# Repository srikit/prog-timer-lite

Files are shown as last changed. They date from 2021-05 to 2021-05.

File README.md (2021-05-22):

# Programmable Timer Module


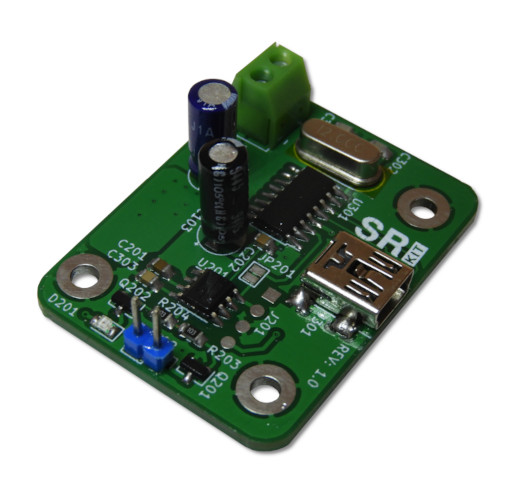
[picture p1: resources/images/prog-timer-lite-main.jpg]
Timer Module PCB


Programmable timer lite is a miniature, USB programmable timer module. This module can handle more than 100 alarm configurations and trigger the output channel based on the programmed conditions. The timer module can program using SRIKit's [*Timer Controller*](https://github.com/srikit/timer-controller) software. 

This module is designed around the *STM8S001J3M* microcontroller and *DS3231* real-time clock. *AMS1117-3.3* regulator in this module can handle a maximum of 9V DC input without installing an external heatsink. 

The alarm terminal of this module is available as an open-collector output. 

This module is specifically developed to handle long-duration alarm configurations which can span up to years. 

This is an open-source hardware project. All the design files, [documentation](https://github.com/srikit/prog-timer-lite/wiki), and firmware source code are available to download at the project source repository. Content of this project is distributed under the terms of the following license:

- Hardware License: [CERN-OHL-W](https://opensource.org/CERN-OHL-W)
- Software License: [GNU GPL 3.0](https://github.com/srikit/prog-timer-lite/blob/main/LICENSE)
- Documentation License: [CC BY 4.0](https://creativecommons.org/licenses/by/4.0)

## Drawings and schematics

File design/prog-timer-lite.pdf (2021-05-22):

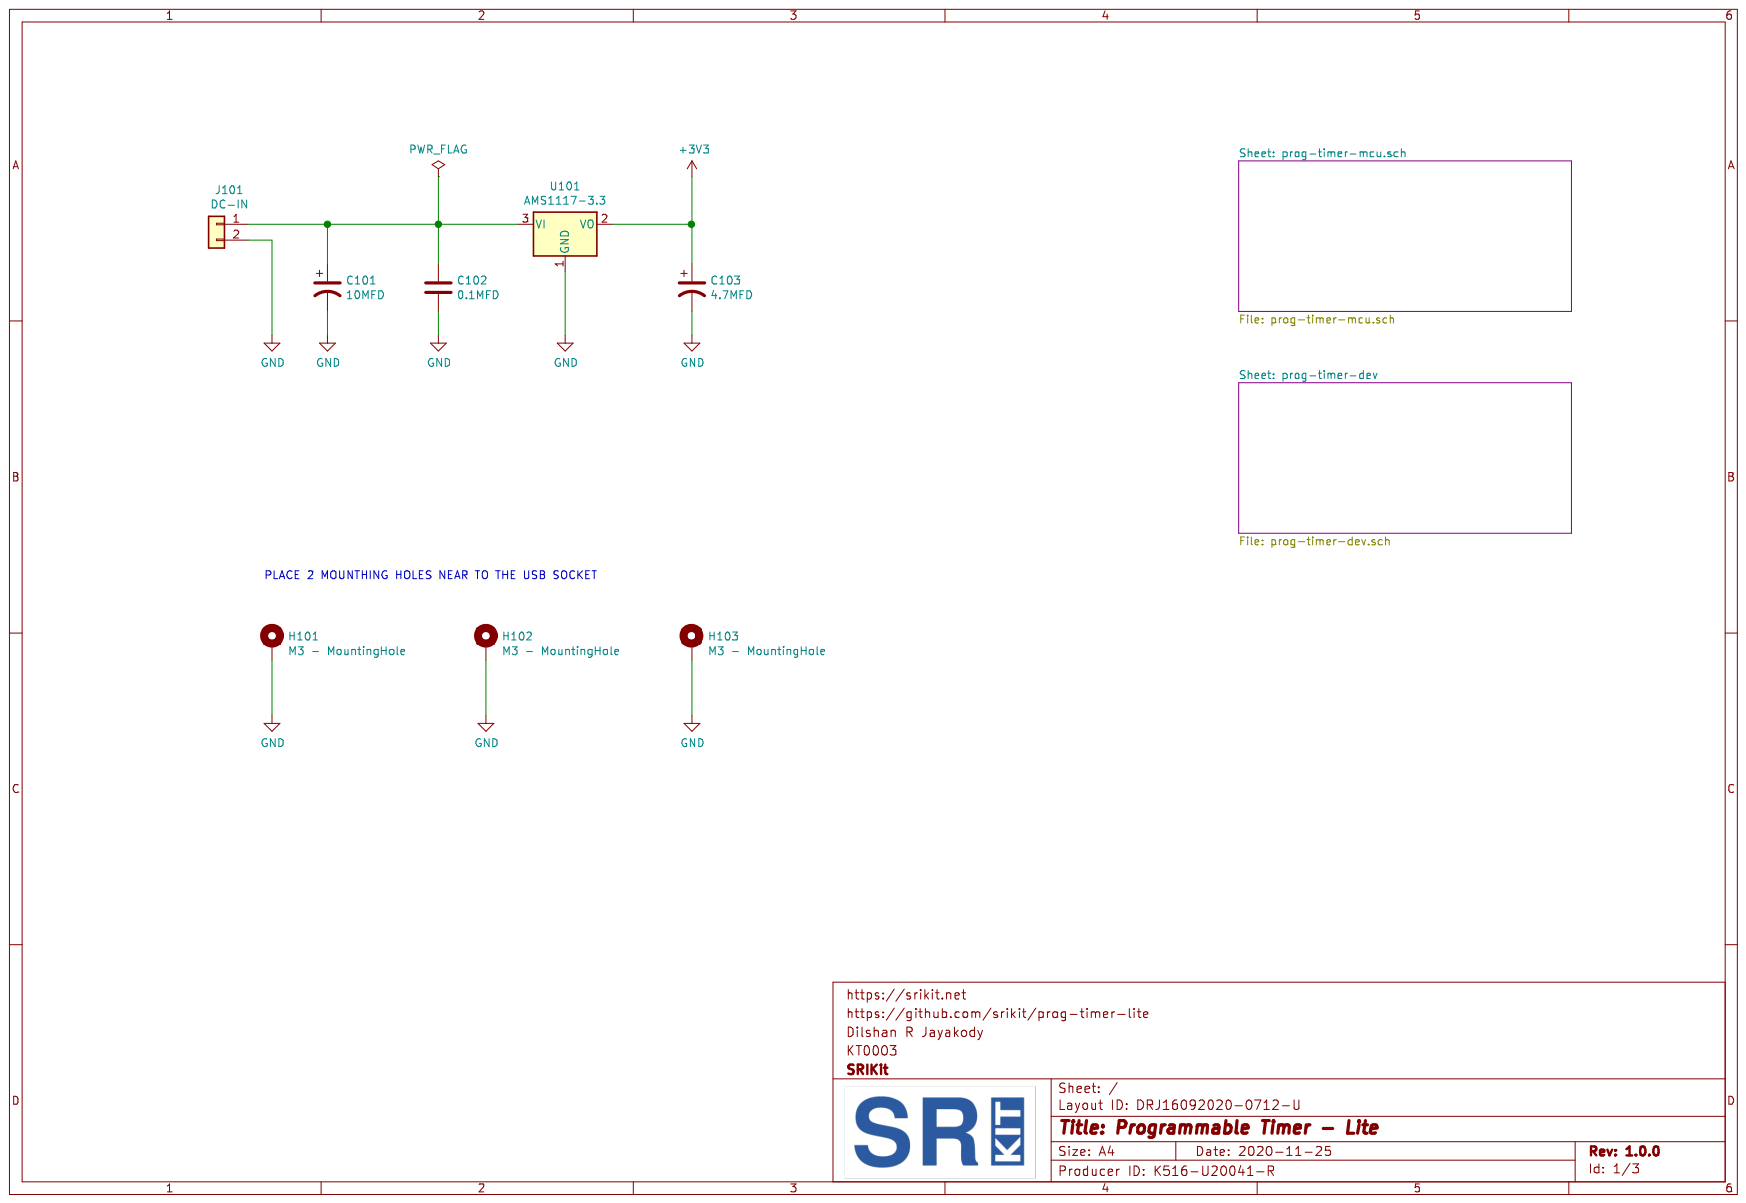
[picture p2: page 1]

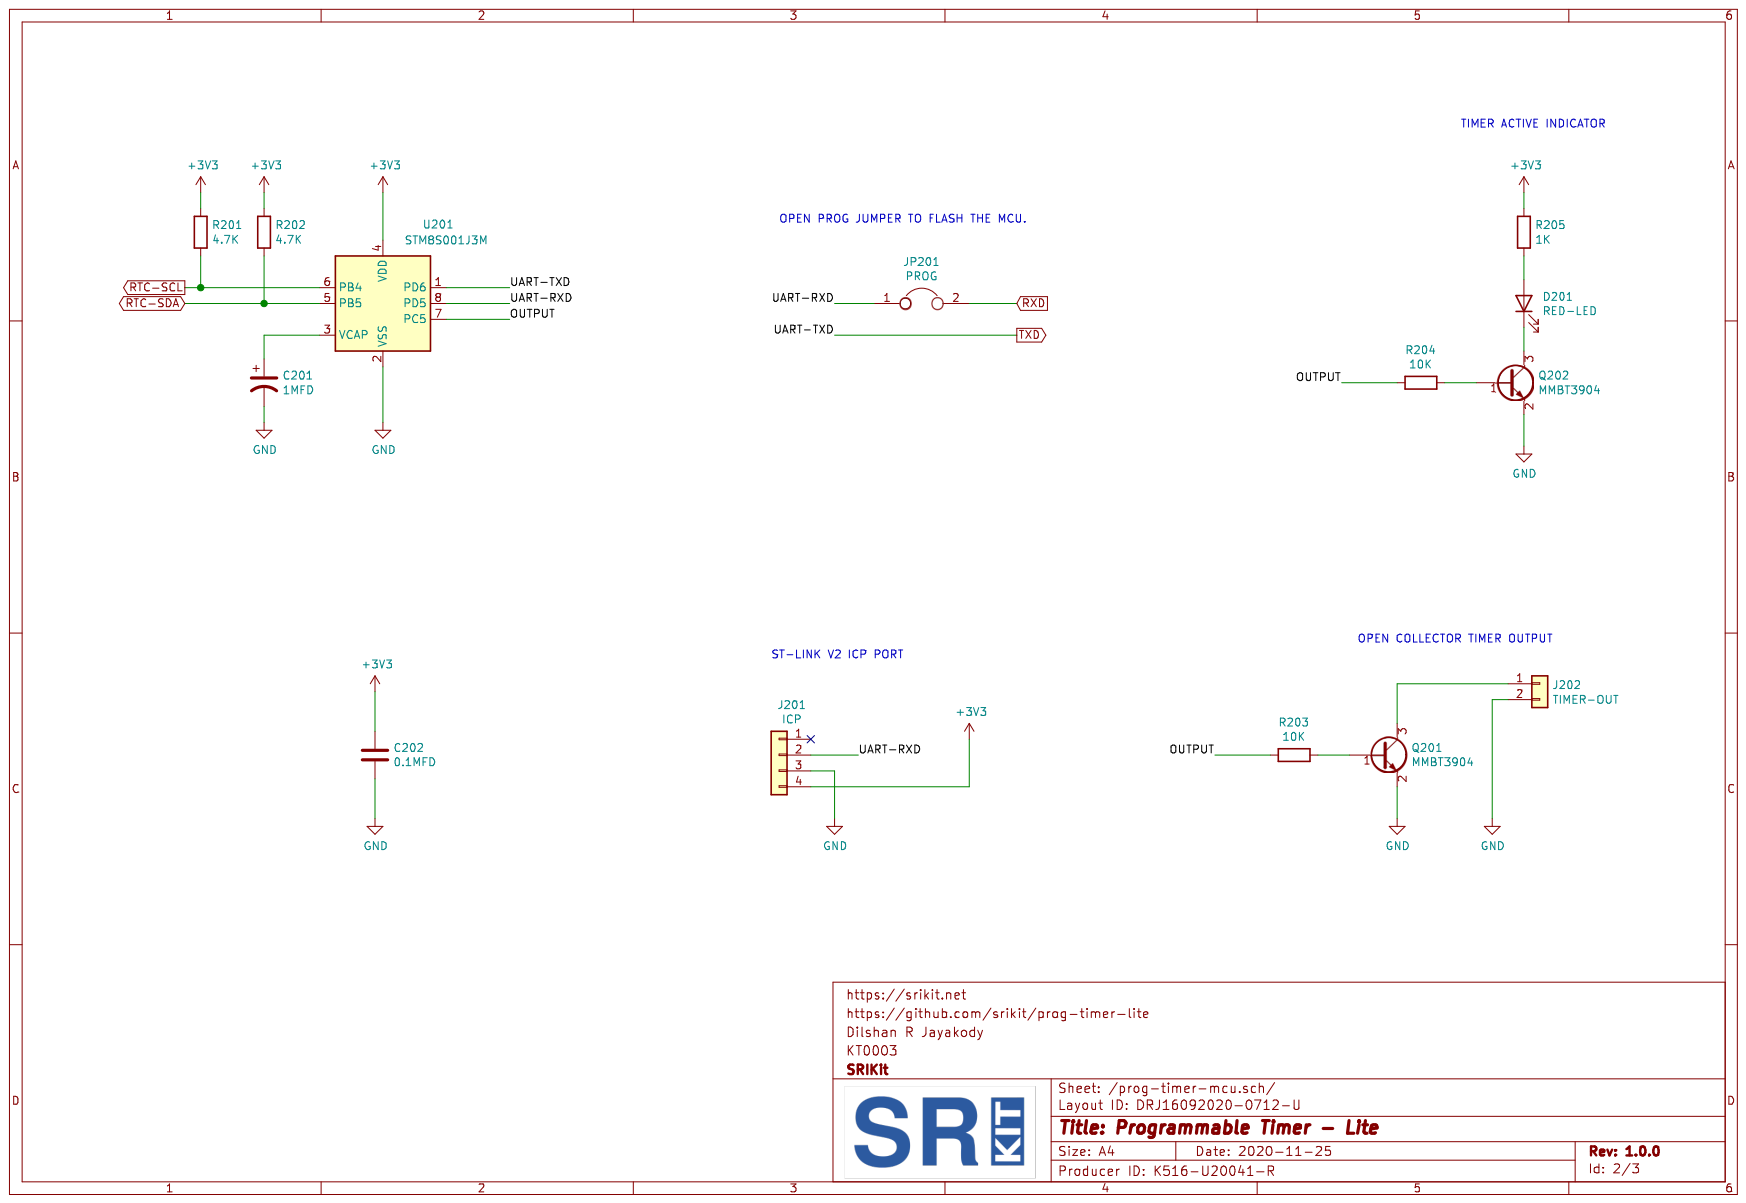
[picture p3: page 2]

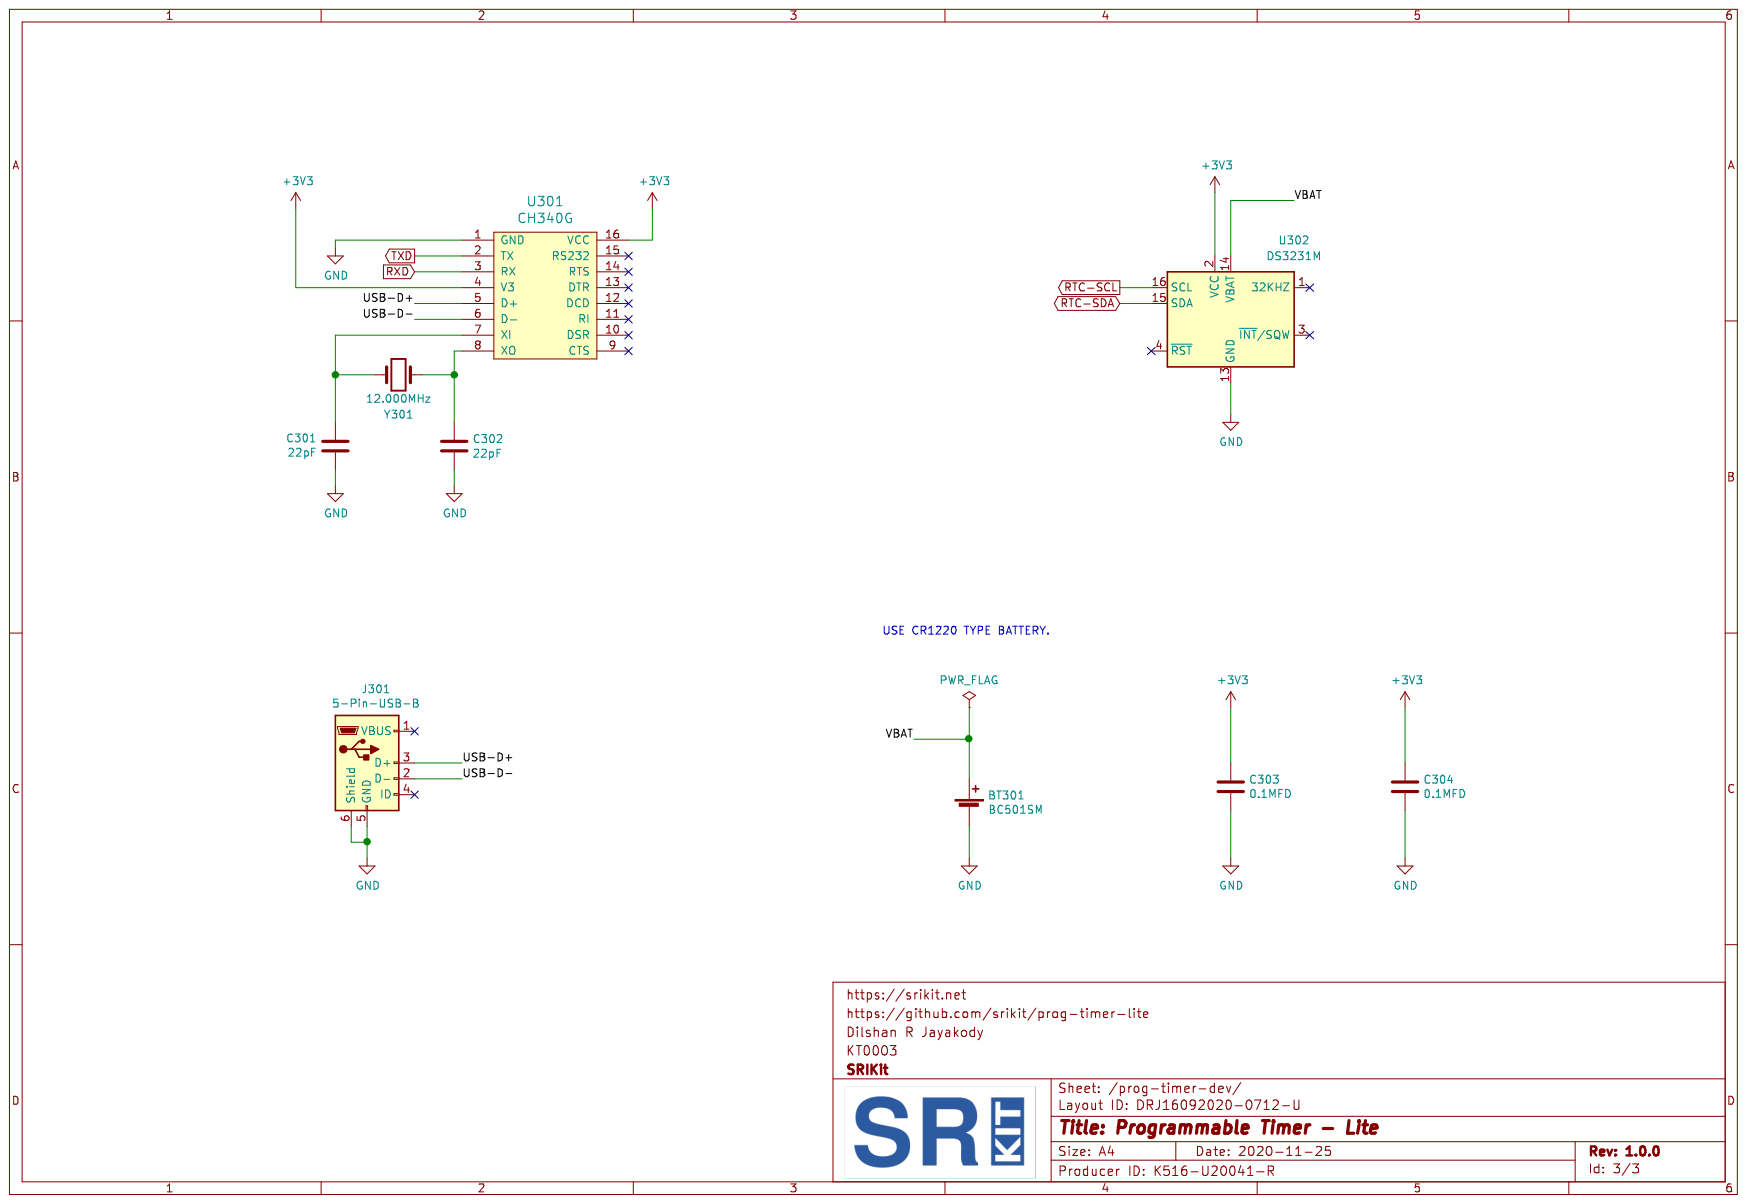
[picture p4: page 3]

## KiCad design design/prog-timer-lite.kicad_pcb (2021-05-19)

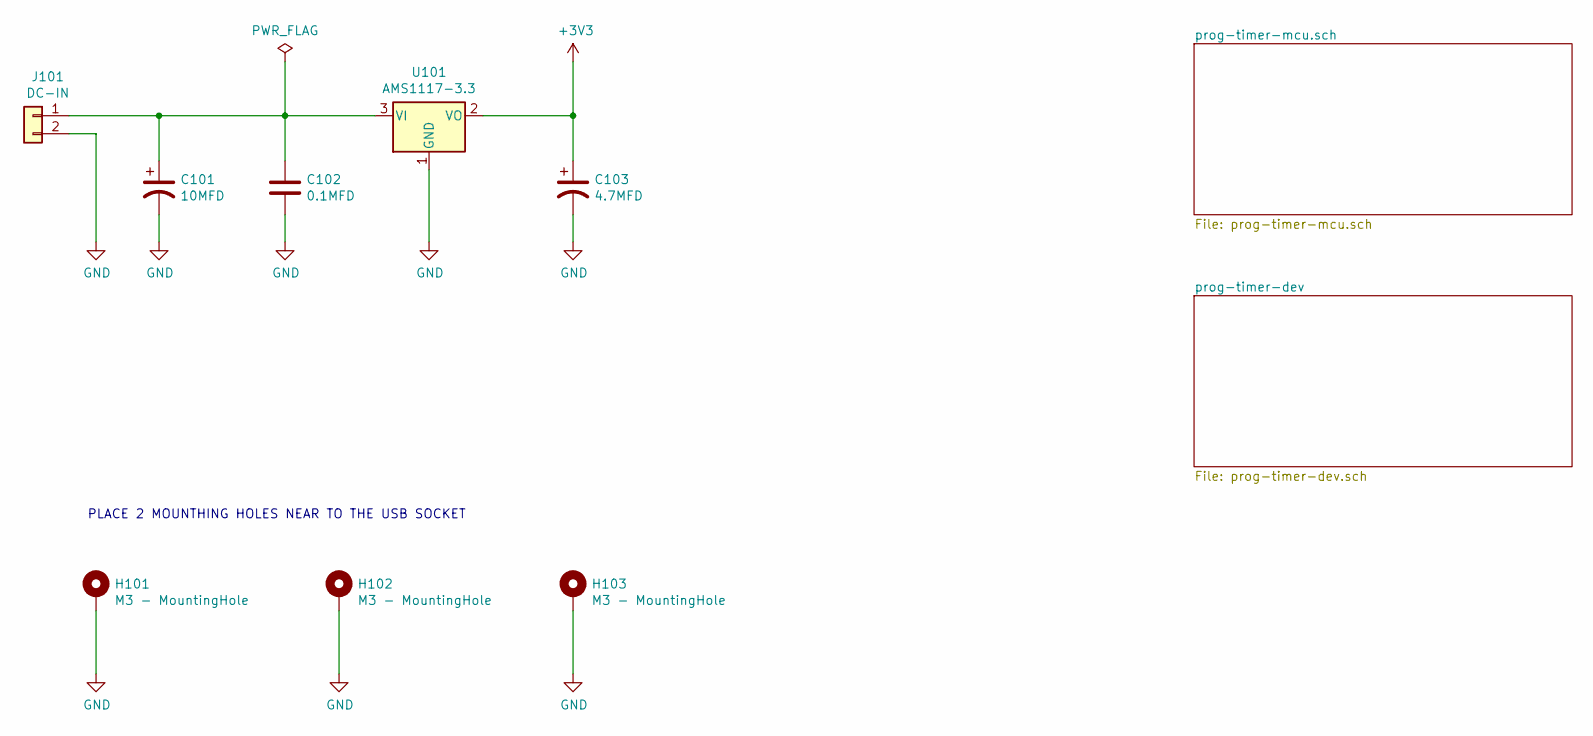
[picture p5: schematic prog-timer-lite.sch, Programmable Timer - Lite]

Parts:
C101: 10MFD; CP_Radial_D5.0mm_P2.50mm
C102: 0.1MFD; C_0805_2012Metric_Pad1.15x1.40mm_HandSolder
C103: 4.7MFD; CP_Radial_D5.0mm_P2.50mm
H101, H102, H103: M3 - MountingHole; MountingHole_3mm_Pad
J101: DC-IN; PhoenixContact_MCV_1,5_2-G-3.5_1x02_P3.50mm_Vertical
U101: AMS1117-3.3; SOT-223-3_TabPin2

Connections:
+3V3: C103.1, U101.2 (VO); also elsewhere on the board
GND: C101.2, C102.2, C103.2, H101.1, H102.1, H103.1, J101.2, U101.1 (GND); also elsewhere on the board
unnamed: C101.1, C102.1, J101.1, U101.3 (VI)

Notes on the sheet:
PLACE 2 MOUNTHING HOLES NEAR TO THE USB SOCKET

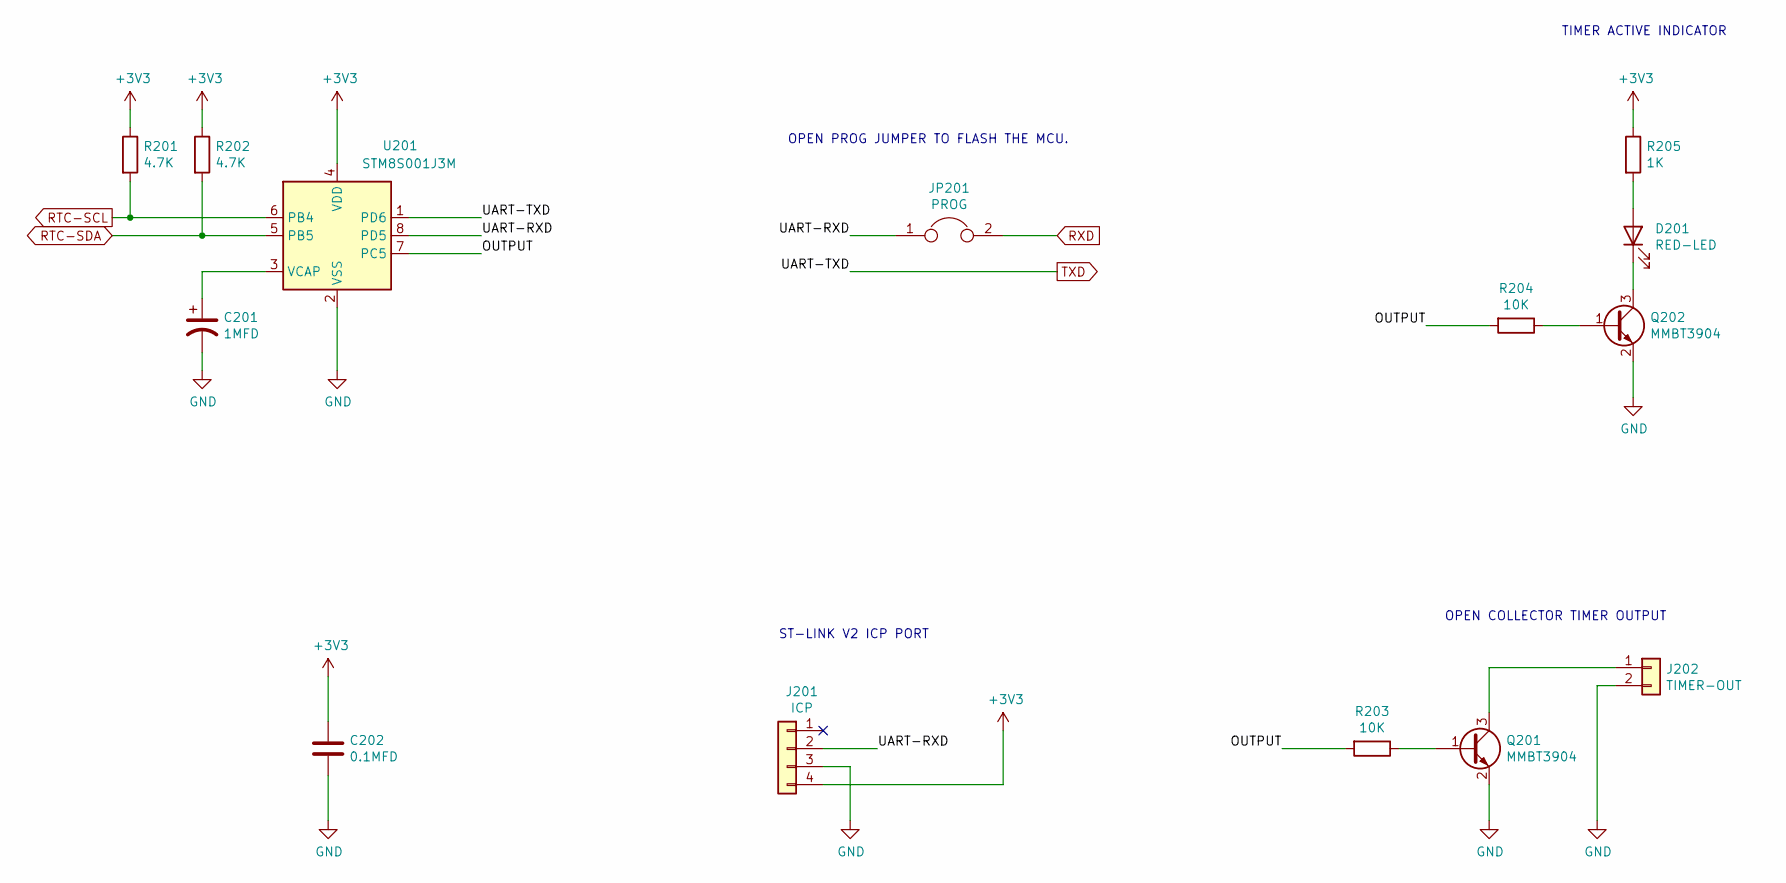
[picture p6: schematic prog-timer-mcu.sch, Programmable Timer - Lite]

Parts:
C201: 1MFD; C_0805_2012Metric_Pad1.15x1.40mm_HandSolder
C202: 0.1MFD; C_0805_2012Metric_Pad1.15x1.40mm_HandSolder
D201: RED-LED; LED_0805_2012Metric_Pad1.15x1.40mm_HandSolder
J201: ICP; pogo-2.54mmx4
J202: TIMER-OUT; PinHeader_1x02_P2.54mm_Vertical
JP201: PROG; SolderJumper-2_P1.3mm_Bridged_Pad1.0x1.5mm
Q201, Q202: MMBT3904; SOT-23
R201, R202: 4.7K; R_0805_2012Metric_Pad1.15x1.40mm_HandSolder
R203, R204: 10K; R_0805_2012Metric_Pad1.15x1.40mm_HandSolder
R205: 1K; R_0805_2012Metric_Pad1.15x1.40mm_HandSolder
U201: STM8S001J3M; SO-8_3.9x4.9mm_P1.27mm

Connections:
+3V3: C202.1, J201.4, R201.1, R202.1, R205.1, U201.4 (VDD); also elsewhere on the board
/prog-timer-mcu.sch/OUTPUT: R203.2, R204.2, U201.7 (PC5)
/prog-timer-mcu.sch/UART-RXD: J201.2, JP201.1, U201.8 (PD5)
GND: C201.2, C202.2, J201.3, J202.2, Q201.2 (E), Q202.2 (E), U201.2 (VSS); also elsewhere on the board
unnamed: C201.1, U201.3 (VCAP)
unnamed: D201.1 (K), Q202.3 (C)
unnamed: D201.2 (A), R205.2
unnamed: J202.1, Q201.3 (C)
unnamed: Q201.1 (B), R203.1
unnamed: Q202.1 (B), R204.1
RTC-SCL: R201.2, U201.6 (PB4); also elsewhere on the board
RTC-SDA: R202.2, U201.5 (PB5); also elsewhere on the board
RXD: JP201.2; also elsewhere on the board
TXD: U201.1 (PD6); also elsewhere on the board

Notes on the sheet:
OPEN PROG JUMPER TO FLASH THE MCU.
TIMER ACTIVE INDICATOR
ST-LINK V2 ICP PORT
OPEN COLLECTOR TIMER OUTPUT

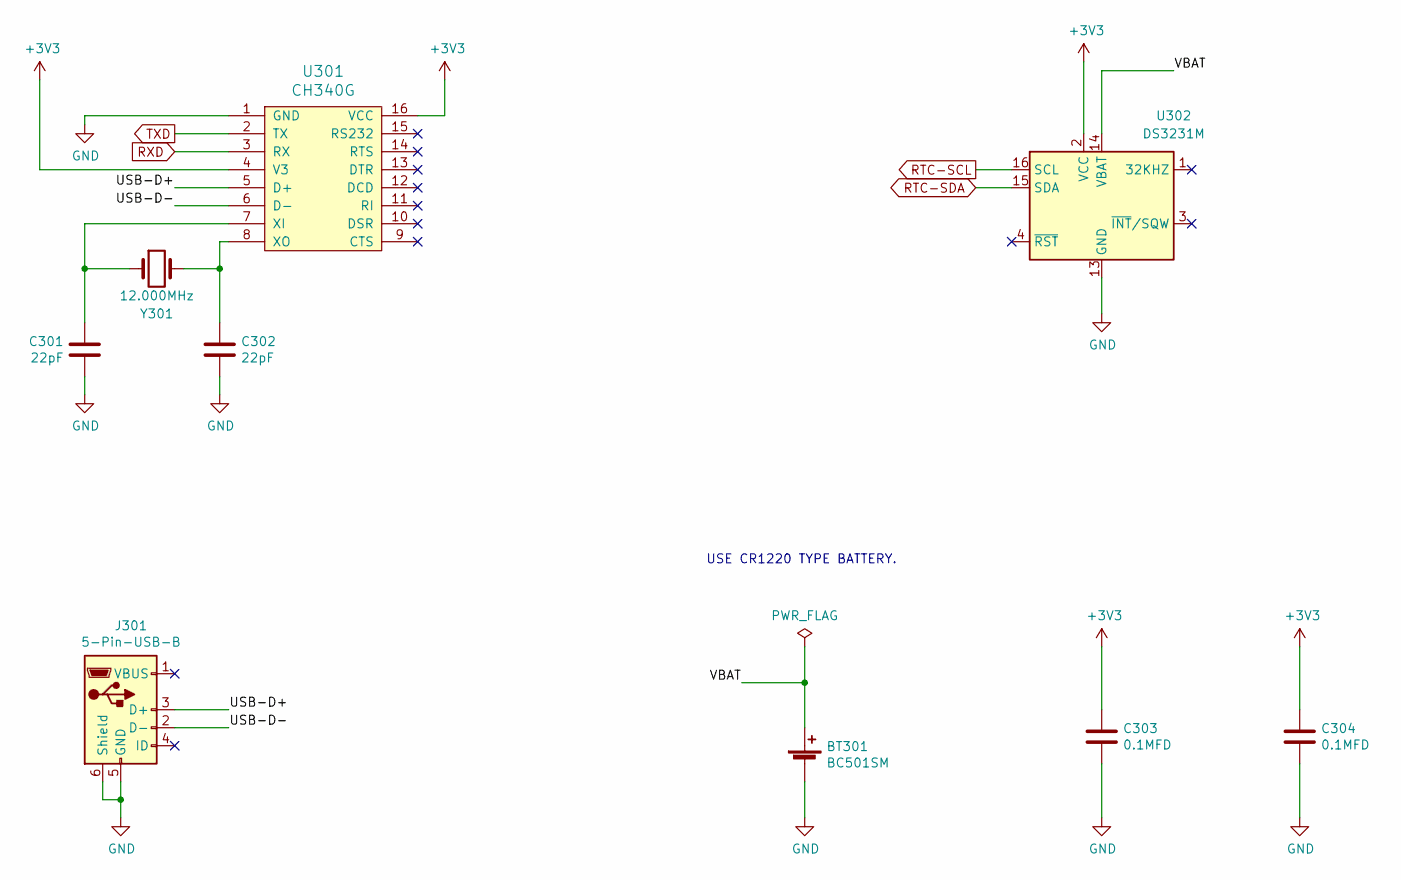
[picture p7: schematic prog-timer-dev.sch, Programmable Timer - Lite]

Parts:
BT301: BC501SM; MPD_BC501SM-TR
C301, C302: 22pF; C_0805_2012Metric_Pad1.15x1.40mm_HandSolder
C303, C304: 0.1MFD; C_0805_2012Metric_Pad1.15x1.40mm_HandSolder
J301: 5-Pin-USB-B; USB_Mini-B_Wuerth_65100516121_Horizontal
U301: CH340G; SOP-16_4.55x10.3mm_P1.27mm
U302: DS3231M; SOIC-16W_7.5x10.3mm_P1.27mm
Y301: 12.000MHz; Crystal_HC49-U_Vertical

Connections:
+3V3: C303.1, C304.1, U301.4 (V3), U301.16 (VCC), U302.2 (VCC); also elsewhere on the board
/prog-timer-dev/USB-D+: J301.3 (D+), U301.5 (D+)
/prog-timer-dev/USB-D-: J301.2 (D-), U301.6 (D-)
/prog-timer-dev/VBAT: BT301.1 (+), U302.14 (VBAT)
GND: BT301.2 (-), C301.1, C302.2, C303.2, C304.2, J301.5 (GND), J301.6 (Shield), U301.1 (GND), U302.5 (GND), U302.6 (GND), U302.7 (GND), U302.8 (GND), U302.9 (GND), U302.10 (GND), U302.11 (GND), U302.12 (GND), U302.13 (GND); also elsewhere on the board
unnamed: C301.2, U301.7 (XI), Y301.1
unnamed: C302.1, U301.8 (XO), Y301.2
RTC-SCL: U302.16 (SCL); also elsewhere on the board
RTC-SDA: U302.15 (SDA); also elsewhere on the board
RXD: U301.3 (RX); also elsewhere on the board
TXD: U301.2 (TX); also elsewhere on the board

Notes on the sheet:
USE CR1220 TYPE BATTERY.

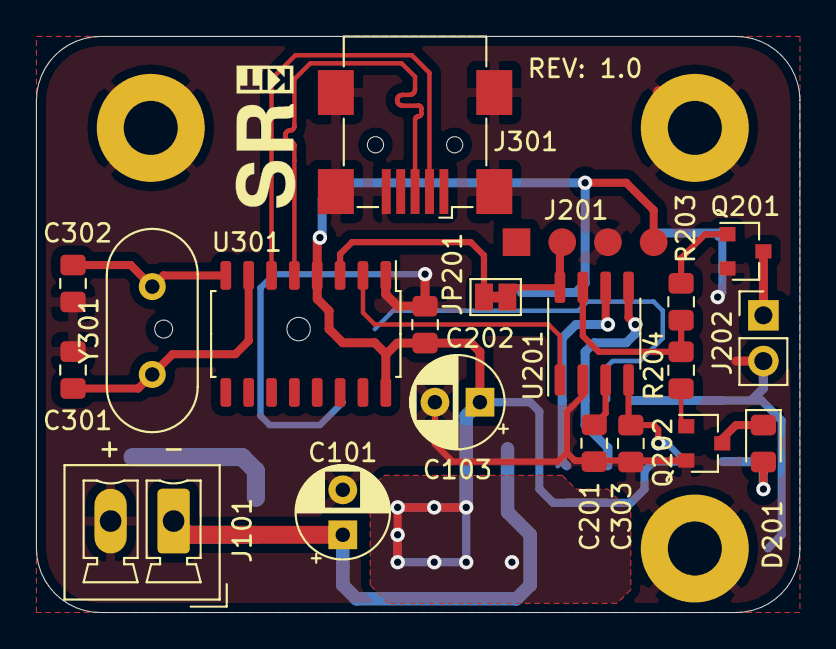
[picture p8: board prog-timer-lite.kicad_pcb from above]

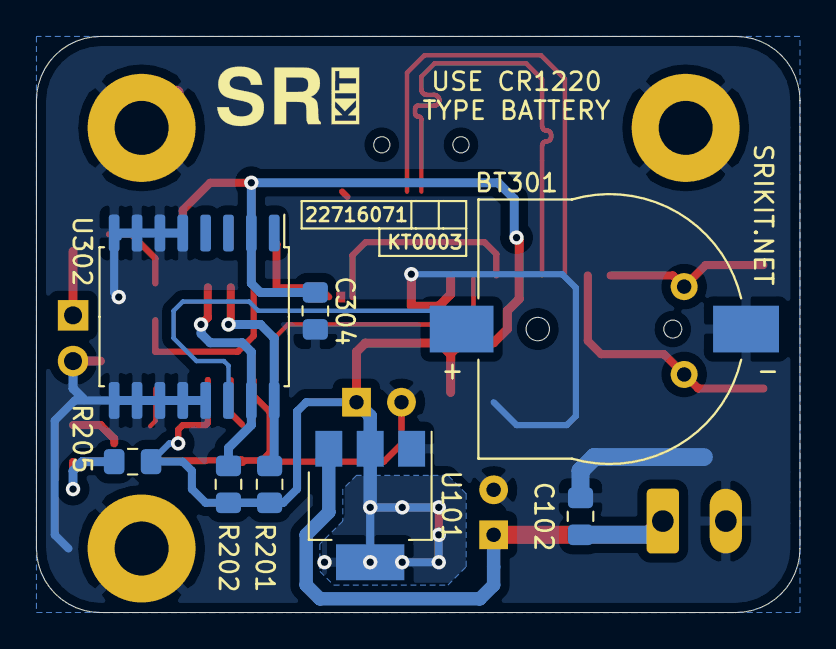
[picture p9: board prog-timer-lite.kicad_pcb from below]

Board: 2 copper layers, 42.4 x 32.0 mm, 31 parts (8 on the bottom side), 20 nets.

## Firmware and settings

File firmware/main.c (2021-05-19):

//-----------------------------------------------------------------------------
// Programmable Timer - Single Channel - Lite Version.
// Main source file.
// 
// Copyright (C) 2020 SriKIT contributors.
//
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
// Last updated: Dilshan Jayakody [24th Nov 2020]
//
// Update log:
// [24/11/2020] - Initial version - Dilshan Jayakody.
//-----------------------------------------------------------------------------

#include "include/stm8.h"
#include "include/stm8-util.h"
#include "include/stm8-uart.h"
#include "include/stm8-eeprom.h"

#include "main.h"
#include "commdata.h"
#include "commresponse.h"
#include "dataconv.h"

// Startup delay limit.
#define INIT_RESET_DELAY    157456

// Size of the input command buffer.
#define DATA_BUFFER_SIZE        19
#define EEPROM_DATA_BLOCK_SIZE  16

#define COMMAND_AVAILABLE   1
#define COMMAND_NOT_FOUND   0

#define ALARM_ON_OUT    0x38
#define ALARM_OFF_OUT   0x00

unsigned char dataBuffer[DATA_BUFFER_SIZE];

void UART_received() __interrupt(UART1_RX_IRQ)
{
    if(uartDataAvailable())
    {
        // UART data is available.  
        dataVal = uartGetByte();  

        // The first byte of the command must be '#', else ignore the command.
        if((dataPos == 0) && (dataVal != COM_HEADER)) 
        {     
            return;
        }

        // Check for valid device command.
        if((dataPos == 1) && (dataVal != COM_DEVICE_HEADER)) 
        {     
            dataPos = 0;
            return;
        }

        // Identify the command type and data length.
        if(dataPos == 2)
        {
            cmdLen = getCommandLen(dataVal);
            if(cmdLen == 0)
            {
                // Unknown command, reset command buffer.
                dataPos = 0;
                return;
            }
        }

        // Update data buffer with received data.
        dataBuffer[dataPos] = dataVal;
        dataPos++; 

        // Check complete command is received to the buffer.
        if((cmdLen > 2) && (dataPos >= cmdLen))
        {
            // Full command is received. Raise the flag!
            exeCommand = COMMAND_AVAILABLE;
        }
    }
}

void main()
{
    // Wait few seconds to provide slot to enter programming / debug mode.
    unsigned long resetTime = 0;
    unsigned char alarmConfigPos, alarmOutput, startIsHigh;
    AlarmInfo currentAlarmConfig;

    for(resetTime = 0; resetTime < INIT_RESET_DELAY; resetTime++); 

    cli();

    // Start device boot.
    initSystem();
    initRTC();
    memClear(dataBuffer, DATA_BUFFER_SIZE);

    // Initialize serial interface with 9600 - 8N1 configuration.
    uartInit();

    // Get system time from RTC.
    getDateTime(&sysTime);

    // Get total number of alarm configurations from EEPROM.
    alarmCount = eepromRead(EEPROM_START_ADDR);

    // Enable UART RX interrupt.
    sei();
    UART1_CR2 |= UART1_CR2_RIEN;

    // Main service loop.
    while(1)
    {
        // UART command processor.
        if(exeCommand)
        {
            // Disable UART RX interrupt while at the command execution.
            UART1_CR2 &= ~UART1_CR2_RIEN;
            
            // Clear command received flag and execute the current command.
            exeCommand = COMMAND_NOT_FOUND;
            executeCommand();

            // Clear command buffer.
            memClear(dataBuffer, DATA_BUFFER_SIZE);
            dataPos = cmdLen = 0;

            // Enable UART RX interrupt.
            UART1_CR2 |= UART1_CR2_RIEN;
        }

        // Get system time from RTC.
        getDateTime(&sysTime);

        // Check for alarm on/off times.
        if(alarmCount > 0)
        {
            alarmConfigPos = 0;
            alarmOutput = 0;
            startIsHigh = 0;

            while(alarmConfigPos < alarmCount)
            {
                getAlarmConfig(&currentAlarmConfig, alarmConfigPos);
                            
                // Check if the date component is disable / enable with this configuration.
                if((currentAlarmConfig.start.year == NULL_YEAR) && (currentAlarmConfig.start.month == 0x00) && (currentAlarmConfig.start.date == 0x00))
                {
                    // Date component is disable in the current alarm configuration.

                    if(currentAlarmConfig.start.hour == currentAlarmConfig.end.hour)
                    {                        
                        if(currentAlarmConfig.start.minute == currentAlarmConfig.end.minute)
                        {
                            startIsHigh = (currentAlarmConfig.start.second > currentAlarmConfig.end.second);
                        }
                        else
                        {
                            startIsHigh = (currentAlarmConfig.start.minute > currentAlarmConfig.end.minute);
                        }
                    }
                    else
                    {
                        startIsHigh = (currentAlarmConfig.start.hour > currentAlarmConfig.end.hour);
                    }
                    
                    // Check for alarm start condition.
                    alarmOutput = IsTimeHigh(&sysTime, &currentAlarmConfig.start);
                    
                    if(startIsHigh)
                    {
                        // Current alarm configuration moves into the next day.
                        if(alarmOutput == 0)
                        {
                            // Check for alarm start conditions in next day.
                            if(sysTime.hour == currentAlarmConfig.end.hour)
                            {
                                if(sysTime.minute == currentAlarmConfig.end.minute)
                                {
                                    alarmOutput = (sysTime.second <= currentAlarmConfig.end.second);
                                }
                                else if(sysTime.minute < currentAlarmConfig.end.minute)
                                {
                                    alarmOutput = 1;
                                }
                            }
                            else if(sysTime.hour < currentAlarmConfig.end.hour)
                            {
                                alarmOutput = 1;
                            }
                        }                        
                    }
                    else
                    {
                        // Both alarm on and off times are in same day.
                        if(alarmOutput)
                        {
                            if(sysTime.hour == currentAlarmConfig.end.hour)
                            {
                                if(sysTime.minute == currentAlarmConfig.end.minute)
                                {
                                    alarmOutput = (sysTime.second < currentAlarmConfig.end.second);
                                }
                                else if(sysTime.minute > currentAlarmConfig.end.minute)
                                {
                                    alarmOutput = 0;
                                }
                            }
                            else if(sysTime.hour > currentAlarmConfig.end.hour)
                            {
                                alarmOutput = 0;
                            }
                        }
                    }                
                }
                else
                {
                    // Both date and time components are enabled in the current alarm configuration.

                    if((currentAlarmConfig.start.year == sysTime.year) && (currentAlarmConfig.start.month == sysTime.month) && (currentAlarmConfig.start.date == sysTime.date))
                    {
                        // Alarm start date is reached. Check for alarm start time.                        
                        alarmOutput = IsTimeHigh(&sysTime, &currentAlarmConfig.start);
                        
                        // Check for alarm end time to shutdown the alarm output.
                        if((alarmOutput) && ((currentAlarmConfig.end.year == sysTime.year) && (currentAlarmConfig.end.month == sysTime.month) && (currentAlarmConfig.end.date == sysTime.date)))
                        {
                            if(sysTime.hour == currentAlarmConfig.end.hour)
                            {
                                if(currentAlarmConfig.end.minute == sysTime.minute)
                                {
                                    alarmOutput = (sysTime.second < currentAlarmConfig.end.second);
                                }
                                else
                                {
                                    alarmOutput = (sysTime.minute < currentAlarmConfig.end.minute);
                                }
                            }
                            else
                            {
                                alarmOutput = (sysTime.hour < currentAlarmConfig.end.hour);
                            }
                        }
                    }
                    else if((currentAlarmConfig.end.year == sysTime.year) && (currentAlarmConfig.end.month == sysTime.month) && (currentAlarmConfig.end.date == sysTime.date))
                    {
                        // Alarm end date is reached. Check for alarm stop time.
                        if(currentAlarmConfig.end.hour == sysTime.hour)
                        {
                            if(currentAlarmConfig.end.minute == sysTime.minute)
                            {
                                alarmOutput = (currentAlarmConfig.end.second > sysTime.second);
                            }
                            else if(currentAlarmConfig.end.minute > sysTime.minute)
                            {
                                alarmOutput = 1;
                            }
                        }
                        else if(currentAlarmConfig.end.hour > sysTime.hour)
                        {
                            alarmOutput = 1;
                        }
                    }
                    else
                    {
                        // Check if the current date is inbetween start and end days.
                        if(sysTime.year == currentAlarmConfig.start.year)
                        {
                            if(sysTime.month == currentAlarmConfig.start.month)
                            {
                                alarmOutput = (sysTime.date >= currentAlarmConfig.start.date);
                            }
                            else if(sysTime.month > currentAlarmConfig.start.month)
                            {
                                alarmOutput = 1;
                            }
                        }
                        else if(sysTime.year > currentAlarmConfig.start.year)
                        {
                            alarmOutput = 1;
                        }
                        
                        // Check for end date.
                        if(alarmOutput)
                        {
                            if(sysTime.year == currentAlarmConfig.end.year)
                            {
                                if(sysTime.month == currentAlarmConfig.end.month)
                                {
                                    alarmOutput = (sysTime.date < currentAlarmConfig.end.date);
                                }
                                else if(sysTime.month > currentAlarmConfig.end.month)
                                {
                                    alarmOutput = 0;
                                }
                            }
                            else if(sysTime.year > currentAlarmConfig.end.year)
                            {
                                alarmOutput = 0;
                            }
                        }
                    }
                }

                // Check for alarm active flag to avoid multipal condition conflits.    
                if(alarmOutput)
                {
                    // Continue alarm configuration only if the alarm output is OFF.
                    break;
                }

                // Move to next alarm configuration.
                alarmConfigPos++;
            }

            // Activate alarm output terminal based on the output flag.
            PC_ODR = (alarmOutput ? ALARM_ON_OUT : ALARM_OFF_OUT);
        }
    }
}

unsigned char getCommandLen(unsigned char cmd)
{
    switch (cmd)
    {
    case COM_CMD_HANDSHAKE:         // Shakehand.
        return COM_LEN_HANDSHAKE;
    case COM_CMD_GET_DEVICE_INFO:   // Get device information.
        return COM_LEN_GET_DEVICE_INFO;
    case COM_CMD_SET_ALARM_START:   // Set alarm start time.
        return COM_LEN_SET_ALARM_START;
    case COM_CMD_SET_ALARM_END:     // Set alarm end time.
        return COM_LEN_SET_ALARM_END;
    case COM_CMD_GET_ALARM_START:   // Get alarm start time.
        return COM_LEN_GET_ALARM_START;
    case COM_CMD_GET_ALARM_END:     // Get alarm end time.
        return COM_LEN_GET_ALARM_END;
    case COM_CMD_SET_SYS_TIME:      // Set system time.
        return COM_LEN_SET_SYS_TIME;
    case COM_CMD_GET_SYS_TIMR:      // Get system time.
        return COM_LEN_GET_SYS_TIME;
    case COM_CMD_SET_TIMER_COUNT:   // Set active alarm count.
        return COM_LEN_SET_TIMER_COUNT;
    case COM_CMD_GET_TIMER_COUNT:   // Get active alarm count.
        return COM_LEN_GET_TIMER_COUNT;
    default:                        // Unknown command and reset the data buffer.
        return 0;
    }
}

void initSystem()
{
    // Setup alarm output terminal.
    PC_DDR = 0x38;
    PC_CR1 = 0x38;
    PC_CR2 = 0x00;
    PC_ODR = ALARM_OFF_OUT;

    // Initialize global variables.
    dataPos = 0;
    cmdLen = 0;
    dataVal = 0;
    exeCommand = 0;
}

unsigned char IsTimeHigh(DateTimeInfo * baseTime, DateTimeInfo * targetTime)
{
    if(baseTime->hour == targetTime->hour)
    {
       if(baseTime->minute == targetTime->minute)
       {
           if(baseTime->second >= targetTime->second)
           {
               return 1;
           }
       }
       else if(baseTime->minute > targetTime->minute)
       {
           return 1;
       }
    }
    else if(baseTime->hour > targetTime->hour)
    {
       return 1;
    }
    
    return 0;
}

void getAlarmConfig(AlarmInfo *info, unsigned char alarmPos)
{
    unsigned short startAddr = EEPROM_START_ADDR + 1 + (EEPROM_DATA_BLOCK_SIZE * alarmPos);

    // Get alarm start configuration.
    info->start.year = eepromRead(startAddr) + NULL_YEAR;
    info->start.month = eepromRead(startAddr + 0x01);
    info->start.date = eepromRead(startAddr + 0x02);
    info->start.hour = eepromRead(startAddr + 0x03);
    info->start.minute = eepromRead(startAddr + 0x04);
    info->start.second = eepromRead(startAddr + 0x05);

    // Get alarm end configuration
    info->end.year = eepromRead(startAddr + 0x06) + NULL_YEAR;
    info->end.month = eepromRead(startAddr + 0x07);
    info->end.date = eepromRead(startAddr + 0x08);
    info->end.hour = eepromRead(startAddr + 0x09);
    info->end.minute = eepromRead(startAddr + 0x0A);
    info->end.second = eepromRead(startAddr + 0x0B);

    // Get channel number from configuration
    info->channel = eepromRead(startAddr + 0x0C);
}

void saveTimeInfo(unsigned short memAddr, unsigned char bufferOffset)
{
    unsigned char strCharBuffer[2];
    unsigned char compVal;

    // Reference: eeprom.txt

    // Extract value of the year.
    byteCopy(strCharBuffer, dataBuffer, bufferOffset); 
    compVal = strToInt(strCharBuffer);
    eepromWrite(memAddr, compVal);          // XY

    // Extract value of the month.
    byteCopy(strCharBuffer, dataBuffer, bufferOffset + 2); 
    compVal = strToInt(strCharBuffer);
    eepromWrite(memAddr + 1, compVal);      // XM

    // Extract value of the date.
    byteCopy(strCharBuffer, dataBuffer, bufferOffset + 4); 
    compVal = strToInt(strCharBuffer);
    eepromWrite(memAddr + 2, compVal);      // XD

    // Extract value of the hour.
    byteCopy(strCharBuffer, dataBuffer, bufferOffset + 6); 
    compVal = strToInt(strCharBuffer);
    eepromWrite(memAddr + 3, compVal);      // XH

    // Extract value of the minute.
    byteCopy(strCharBuffer, dataBuffer, bufferOffset + 8); 
    compVal = strToInt(strCharBuffer);
    eepromWrite(memAddr + 4, compVal);      // XN

    // Extract value of the seconds.
    byteCopy(strCharBuffer, dataBuffer, bufferOffset + 10); 
    compVal = strToInt(strCharBuffer);
    eepromWrite(memAddr + 5, compVal);      // XS
}

void readTimeInfo(unsigned short memAddr)
{
    unsigned char strCharBuffer[2];
    unsigned char tmpVal;
    
    // Extract year and send it via UART.
    tmpVal = eepromRead(memAddr);
    IntToStr(tmpVal, strCharBuffer);
    uartWrite(strCharBuffer[0]);
    uartWrite(strCharBuffer[1]);

    // Extract month and send it via UART.
    tmpVal = eepromRead(memAddr + 1);
    IntToStr(tmpVal, strCharBuffer);
    uartWrite(strCharBuffer[0]);
    uartWrite(strCharBuffer[1]);

    // Extract date and send it via UART.
    tmpVal = eepromRead(memAddr + 2);
    IntToStr(tmpVal, strCharBuffer);
    uartWrite(strCharBuffer[0]);
    uartWrite(strCharBuffer[1]);

    // Extract hour and send it via UART.
    tmpVal = eepromRead(memAddr + 3);
    IntToStr(tmpVal, strCharBuffer);
    uartWrite(strCharBuffer[0]);
    uartWrite(strCharBuffer[1]);

    // Extract minute and send it via UART.
    tmpVal = eepromRead(memAddr + 4);
    IntToStr(tmpVal, strCharBuffer);
    uartWrite(strCharBuffer[0]);
    uartWrite(strCharBuffer[1]);

    // Extract second and send it via UART.
    tmpVal = eepromRead(memAddr + 5);
    IntToStr(tmpVal, strCharBuffer);
    uartWrite(strCharBuffer[0]);
    uartWrite(strCharBuffer[1]);
}

void updateSysTime()
{
    unsigned char strCharBuffer[2];
    DateTimeInfo tempSysTime;

    // Get year from the input buffer.
    byteCopy(strCharBuffer, dataBuffer, 3); 
    tempSysTime.year = strToInt(strCharBuffer);
    
    // Get month from the input buffer.
    byteCopy(strCharBuffer, dataBuffer, 5); 
    tempSysTime.month = strToInt(strCharBuffer);

    // Get date from the input buffer.
    byteCopy(strCharBuffer, dataBuffer, 7); 
    tempSysTime.date = strToInt(strCharBuffer);

    // Get hour from the input buffer.
    byteCopy(strCharBuffer, dataBuffer, 9); 
    tempSysTime.hour = strToInt(strCharBuffer);

    // Get minute from the input buffer.
    byteCopy(strCharBuffer, dataBuffer, 11); 
    tempSysTime.minute = strToInt(strCharBuffer);

    // Get seconds from the input buffer.
    byteCopy(strCharBuffer, dataBuffer, 13); 
    tempSysTime.second = strToInt(strCharBuffer);

    // Update RTC time.
    setDateTime(&tempSysTime);
}
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

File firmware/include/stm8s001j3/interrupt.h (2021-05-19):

//-----------------------------------------------------------------------------
// STM8S001J3 IRQ mapping header file for SDCC.
// 
// Copyright (C) 2020 SriKIT contributors.
//
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
// Based on STM8S001J3 datasheet DS12129 Rev 4.
// Last updated: Dilshan Jayakody [1st Nov 2020]
//
// Update log:
// [01/11/2020] - Initial version - Dilshan Jayakody.
//-----------------------------------------------------------------------------

#ifndef STM8S001_INTERRUPT_MAP_H
#define STM8S001_INTERRUPT_MAP_H

#define EXTERNAL_TOP_LEVEL_IRQ      0       // External top level interrupt.
#define AUTO_WAKE_HALT_IRQ          1       // Auto wake up from halt.

#define CLK_IRQ                     2       // Clock controller.

#define PORTA_IRQ                   3       // Port A external interrupts.
#define PORTB_IRQ                   4       // Port B external interrupts.
#define PORTC_IRQ                   5       // Port C external interrupts.
#define PORTD_IRQ                   6       // Port D external interrupts.
#define PORTE_IRQ                   7       // Port E external interrupts.

#define SPI_END_TRANSFER_IRQ        10      // SPI end of transfer.

#define TIMER1_TRIGGER_IRQ          11      // TIMER1 update/overflow/underflow/trigger/break.
#define TIMER1_COMPARE_IRQ          12      // TIMER1 capture/compare.

#define TIMER2_TRIGGET_IRQ          13      // TIMER2 update /overflow.
#define TIMER2_COMPARE_IRQ          14      // TIMER2 capture/compare.

#define UART1_TX_IRQ                17      // UART1 TX (send) complete.
#define UART1_RX_IRQ                18      // UART1 RX (receive) register is full.

#define IIC_IRQ                     19      // I2C interrupt.

#define ADC1_COMPLETE_IRQ           22      // ADC1 end of conversion/analog watchdog interrupt.

#define TIMER4_TRIGGET_IRQ          23      // TIMER4 update/overflow.

#define FLASH_IRQ                   24      // Flash memory end of operation / WR_PG_DIS.

#endif /* STM8S001_INTERRUPT_MAP_H */

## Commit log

2021-05-19 Initial version of programmable timer module firmware and design files.
    [prog-timer-dev.sch, prog-timer-lite.kicad_pcb, prog-timer-lite.sch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]
2021-05-19 Add link to Timer Programmer Git repository.
2021-05-21 Update link description of the Timer Controller.
2021-05-22 Add graphics, fritzing packages and CAD drawing of the module.
2021-05-22 Add image of the PCB to the readme.md file.
2021-05-22 Add Fritzing diagram for test setup.
    [prog-timer-test-setup.fzz]
2021-05-22 Add PDF version of the schematic diagram.

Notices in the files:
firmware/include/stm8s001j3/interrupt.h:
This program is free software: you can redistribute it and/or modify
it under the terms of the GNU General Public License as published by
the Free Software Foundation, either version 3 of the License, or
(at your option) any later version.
